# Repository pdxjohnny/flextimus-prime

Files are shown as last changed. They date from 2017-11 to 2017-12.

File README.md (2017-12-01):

# Flextimus Prime

Posture monitor

## Getting Started

Make sure you have git configured.

```console
git config --global user.name 'Frist Last'
git config --global user.email 'first.last@example.com'
```

Install the git commit hooks. This will ensure that you can only commit if the
source compiles successfully.

> **WARNING** This adds `set auto-load safe-path /` to your `~/.gdbinit` which
> is not safe because when you start gdb it will now execute any commands in the
> `.gdbinit` file in the current directory.

```console
./scripts/install.sh
```

Find out what you should work on

```console
git todo
```

> This will be run every time you pull so that see todos added by others.

Create a new branch for your work

```console
git checkout -b describe_my_intended_changes
```

Now connect the board, and start `st-util`. From the the top level of this repo
run `arm-none-eabi-gdb` or `make gdb`.

Start hacking!

### Dependencies

1. [mbed](https://os.mbed.com/docs/v5.6/tools/setup.html)

## Contributing

See [CONTRIBUTING.md](https://github.com/pdxjohnny/flextimus-prime/blob/master/CONTRIBUTING.md)

## Team

- Max (lead)
- Julian
- John
- fouric

> Fall 2017
> Practicum Project

## Description

Your team will be responsible for designing, constructing, and demonstrating a small project as part of the course. The project is intended to both give you some necessary implementation skills and experience as well as serve as a model for your capstone experience. In fact, the capstone evaluation forms and worksheets will be used in evaluating and grading your practicum project.

You will get experience with PCB schematic and layout tools, project documentation and management tools, revision control systems, PCB assembly, and (depending upon your project) microcontroller IDEs.

Equally important, you will create project requirements, test plans, schedules, and documentation as you would for your capstone project (or a project in industry). Requirements Your project can do almost anything but must satisfy the following course requirements:

- Have one or more inputs or sensors
  - e.g. photodiodes, switches, accelerometers, pressure sensor, network data (wired or wireless), etc.

- Have one or more outputs or transducers
  - e.g. LEDs, LCDs, motors, networking (wired or wireless).

- Have one or more processing modules which control some of the outputs based on the inputs
  - e.g. analog filters, microcontrollers, FPGAs, etc.

- Use a two layer PCB that is between 1 and 16 in 2, with no side of the board being less than 1 inch or more than 12 inches.

- Use components that can be hand soldered or easily soldered in a crude reflow oven (no BGAs, uBGAs, LGAs, or components smaller than 0603 packages allowed)

## Grading Criteria

Your project will be evaluated using the capstone evaluation forms found on the capstone web site.

Portions of your practicum are evaluated separately throughout the course as part of the homework assignments.

Other aspects are evaluated as part of your project demonstration (final project presentation, design documentation, communication (e.g. weekly progress reports)). Originality Ideally, you should choose an original project idea or a new implementation of an existing idea. To receive an A on the practicum project you must not use existing work (unless specifically approved in advance by the instructor in writing).

If you choose to implement an existing design or incorporate existing work (including but not limited to schematics, layout, or code), your maximum achievable grade is a B.

However, you must disclose both what you've borrowed and the source.

Use of existing work that is not disclosed will result in a practicum grade of F. Recommendation It's far more important that your project be complete and functioning than complex. It's essential that you complete all aspects of the project from idea generation through requirements definition, design description/modeling, layout, construction, test, debug, and documentation.

It's important that you demonstrate a working project. A simple project designed and implemented completely by the team using the disciplined design process taught in class and demonstrably working will beat out an overly ambitious project that's incomplete, non-functioning, or haphazardly implemented.

Consider this in choosing a project. That's not to suggest you shouldn't be imaginative or ambitious. Everything else being equal, a creative points.

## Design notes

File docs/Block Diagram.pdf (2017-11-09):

# Flextimus Prime

# Posture Detection Device

## Julian Saunders Max Schweitzer John Anderson Grant Vesely

Posture | Detection | Device: | Level | 0

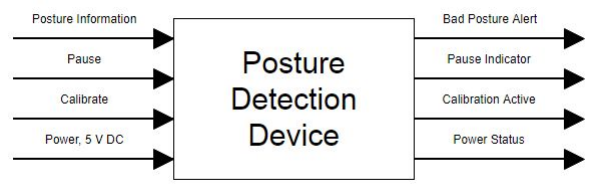
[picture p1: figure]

Module | Posture Detection Device
Inputs | Posture Information: The range of values from the sensor that are considered either good or bad for posture. Pause: Stop the alert system for some amount of time. Calibrate: Change range that the system defines as “good” posture. Power: 5 V DC source from USB connection.
Outputs | Bad Posture Alert: Signals the user that they have bad posture. Pause Indicator: Tells the user that the system is paused. Calibration Active: Tells the user that the system is in calibration mode. Power Status: Displays if the system has power.
Functionality | Takes a range of values from a flex sensor based on the user’s posture. The values considered good can be changed by the user. If the user’s posture is out of the acceptable range then they are notified by a buzzer. The notification of bad posture can be paused.

Posture | Detection | Device: | Level | 1

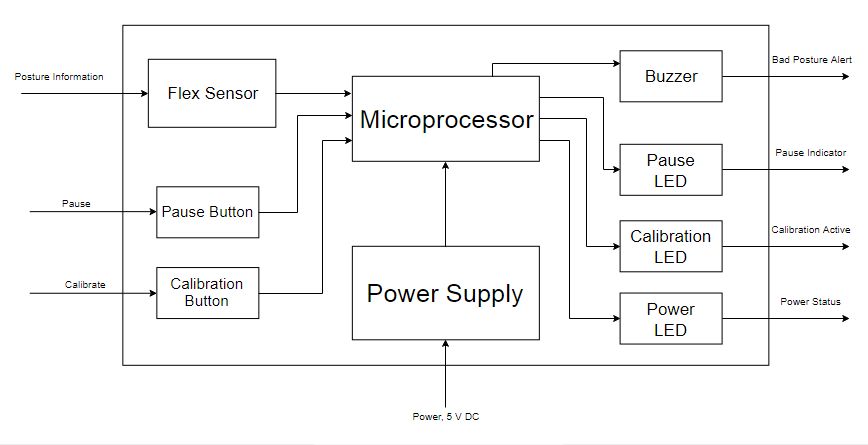
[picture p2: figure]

Microprocessor: | Level | 1

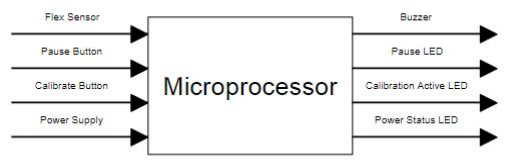
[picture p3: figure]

Module | Microprocessor
Inputs | Flex Sensor: Receives a variable voltage from the flex sensor. Pause Button: Signal to the processor to stop alerts. Calibrate Button: Signal to the processor to begin calibration. Power Supply: 3.3 V DC
Outputs | Buzzer: Signal to activate the buzzer alert. Pause LED: Signal to turn on the LED when paused.. Calibration LED: Signal to turn on the LED when calibrating. Power Status LED: Signal to LED indicating system has power.
Functionality | Receives signals from hardware and produces appropriate output signals based on the combination of input signals and code constraints. Does any necessary internal calculations.

Flex | Sensor: | Level | 1

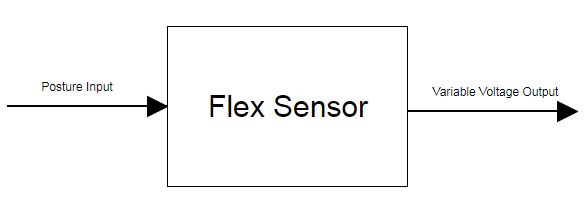
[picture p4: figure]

Module | Flex Sensor
Inputs | Posture Input: Based on how far the user moves their body (neck, back, wrists, etc.)
Outputs | Variable Voltage Output: Outputs a voltage that depends on how bent the flex sensor is.
Functionality | Converts how bent a desired part of the body is into a voltage value that can be used by the processor track posture. The resistance of the flex sensor changes with how much it is bent.

Pause | Button: | Level | 1

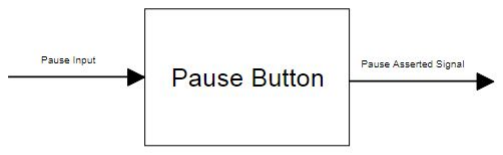
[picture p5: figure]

Module | Pause Button
Inputs | Pause Input: Button press from user.
Outputs | Pause Asserted Signal: Logic High.
Functionality | Gives the user a way to tell the processor to stop sending the alert signal for some period of time or potentially until pressed again.

Calibration | Button: | Level | 1

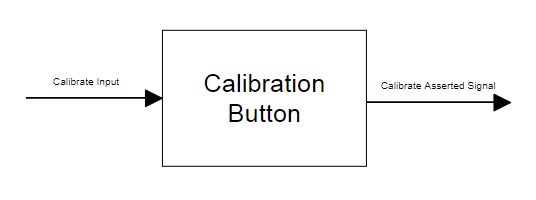
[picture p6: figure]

Module | Calibrate Button
Inputs | Calibrate Input: Button press from user.
Outputs | Calibrate Asserted Signal: Logic High.
Functionality | Allows the user to set their own desired range of accepted values for good posture.

Buzzer: | Level | 1

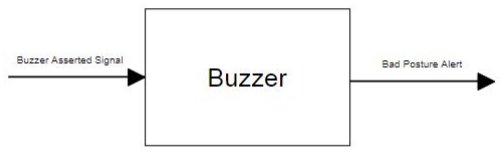
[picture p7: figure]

Module | Buzzer
Inputs | Buzzer Asserted Signal: Signal from processor when a posture violation has occurred.
Outputs | Bad Posture Alert: Buzzer activation
Functionality | Buzzer to vibrate and make noise to alert the user that their posture is bad. Stops when user resumes a good posture.

Pause | LED: | Level | 1

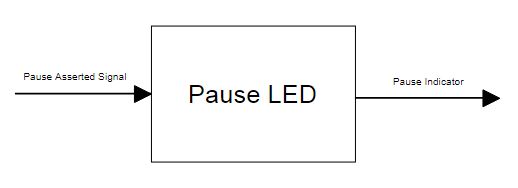
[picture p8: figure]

Module | Pause LED
Inputs | Pause Asserted Signal: Signal from processor that system is paused.
Outputs | Pause Indicator: LED turns on/off.
Functionality | LED that tells the user that the system is in pause mode when lit and bad posture violations will not be reported.

Calibrate | LED: | Level | 1

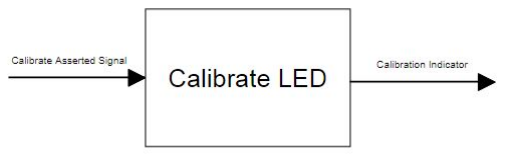
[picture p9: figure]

Module | Calibrate LED
Inputs | Calibrate Asserted Signal: Signal from processor that the system is in calibration mode.
Outputs | Calibration Indicator: LED turns on/off.
Functionality | When lit, indicates that the system is in calibration mode and is recording new maximum values for the range of legal motion.

Power | LED: | Level | 1

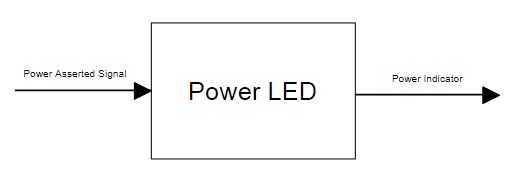
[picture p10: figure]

Module | Power LED
Inputs | Power Asserted Signal: Signal from processor or possibly tied to power supply.
Outputs | Power Indicator: LED turns on/off.
Functionality | LED on indicates the system has power.

Power | Supply: | Level | 1

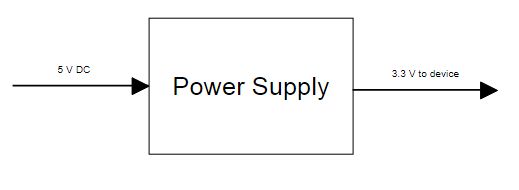
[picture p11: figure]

Module | Power Supply
Inputs | 5 V DC: Power
Outputs | 3.3 V to device: Power to the Microprocessor.
Functionality | Powers the device with desired values.

Power | Supply: | Level | 2

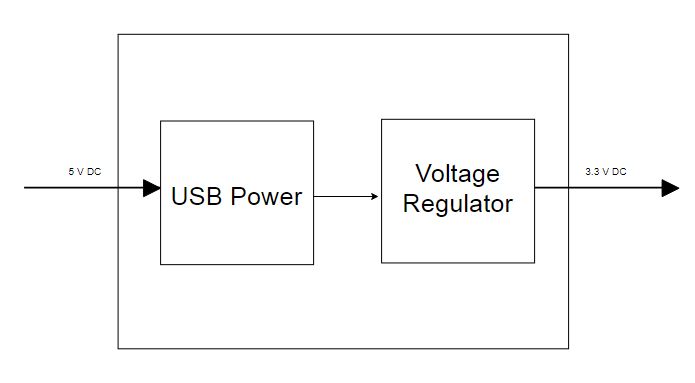
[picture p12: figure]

USB | Power: | Level | 2

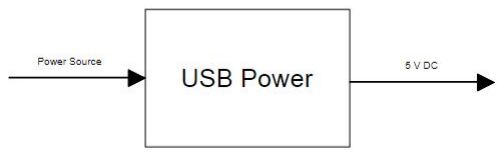
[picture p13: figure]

Module | USB Power
Inputs | Power Source: Plug from USB port.
Outputs | 5 V DC: Output to power supply system.
Functionality | Main connection for powering the device.

Voltage | Regulator: | Level | 2

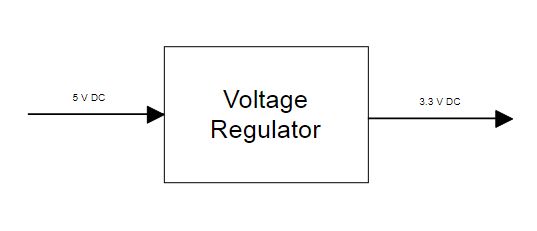
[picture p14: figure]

Module | Voltage Regulator
Inputs | 5 V DC: From USB power.
Outputs | 3.3 V DC: to processor.
Functionality | Converts the 5 volt input from the USB power to 3.3 volts for the processor.

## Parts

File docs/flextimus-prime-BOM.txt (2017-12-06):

Partlist exported from C:/Users/Crimson/AppData/Local/Temp/Rar$DIa0.229/flextimus-prime.sch at 11/30/2017 9:41 PM

Part Value             Device                          Package                  Description                                       COPYRIGHT                                                 MANUFACTURER_PART_NUMBER MF MPN OC_FARNELL OC_NEWARK PROD_ID     SF_SKU    TP_SIGNAL_NAME VALUE    VENDOR            
C1   100n              C-EUC0805                       C0805                    CAPACITOR, European symbol                                                                                                                                                                                                       
C2   100n              C-EUC0805                       C0805                    CAPACITOR, European symbol                                                                                                                                                                                                       
C4   10uf              C-EUC0805                       C0805                    CAPACITOR, European symbol                                                                                                                                                                                                       
C5   10uf              C-EUC0805                       C0805                    CAPACITOR, European symbol                                                                                                                                                                                                       
C6   0.1uf             C-EUC0805                       C0805                    CAPACITOR, European symbol                                                                                                                                                                                                       
C7   10uf              C-EUC0805                       C0805                    CAPACITOR, European symbol                                                                                                                                                                                                       
C8   0.1uf             C-EUC0805                       C0805                    CAPACITOR, European symbol                                                                                                                                                                                                       
CN2                    USBMINIB                        USB-MINIB                USB Connectors                                                                                                                                                                                                                   
D1                     LED10MM                         LED_10MM                 LED (Generic)                                                                                                                                                                                                                    
D2                     LED10MM                         LED_10MM                 LED (Generic)                                                                                                                                                                                                                    
D3                     LED10MM                         LED_10MM                 LED (Generic)                                                                                                                                                                                                                    
FB1  2.5kO/50mA        FERRITE_BEAD-0603               0603                     Ferrite Bead (blocks, cores, rings, chokes, etc.)                                                                                                                NDUC-07859                           30O/1.8A                   
JP1                    PINHD-1X2                       1X02                     PIN HEADER                                                                                                                                                                                                                       
JP2                    PINHD-1X2                       1X02                     PIN HEADER                                                                                                                                                                                                                       
JP3                    PINHD-1X16                      1X16                     PIN HEADER                                                                                                                                                                                                                       
JP5                    JP1E                            JP1                      JUMPER                                                                                                                                                                                                                           
JP6                    PINHD-2X10                      2X10                     PIN HEADER                                                                                                                                                                                                                       
R1   6k                R-US_R0805                      R0805                    RESISTOR, American symbol                                                                                                                                                                                                        
R2   6k                R-US_R0805                      R0805                    RESISTOR, American symbol                                                                                                                                                                                                        
R3   330               R-US_R0805                      R0805                    RESISTOR, American symbol                                                                                                                                                                                                        
R4   330               R-US_R0805                      R0805                    RESISTOR, American symbol                                                                                                                                                                                                        
R5   10k               R-US_R0805                      R0805                    RESISTOR, American symbol                                                                                                                                                                                                        
R6   10k               R-US_R0805                      R0805                    RESISTOR, American symbol                                                                                                                                                                                                        
R7   10k               R-US_R0805                      R0805                    RESISTOR, American symbol                                                                                                                                                                                                        
R8   10k               R-US_R0805                      R0805                    RESISTOR, American symbol                                                                                                                                                                                                        
R9   10k               R-US_R0805                      R0805                    RESISTOR, American symbol                                                                                                                                                                                                        
R10  10k               R-US_R0805                      R0805                    RESISTOR, American symbol                                                                                                                                                                                                        
S1   SPST              MOMENTARY-SWITCH-SPST-PTH-6.0MM TACTILE_SWITCH_PTH_6.0MM Momentary Switch (Pushbutton) - SPST                                                                                                                              SWCH-08441 COM-00097                                           
S2   SPST              MOMENTARY-SWITCH-SPST-PTH-6.0MM TACTILE_SWITCH_PTH_6.0MM Momentary Switch (Pushbutton) - SPST                                                                                                                              SWCH-08441 COM-00097                                           
SG1  F/CM04P           F/CM04P                         F/CM04P                  BUZZER Source: Buerklin                                                                                                                     unknown    unknown                                                                   
T1   2N2222            2N2222                          TO92-EBC-OVAL            NPN TRANSISTOR                                                                                                                                                                                                                   
TP1  TPB2,54           TPB2,54                         B2,54                    Test pad                                                                                                                                                                                                                         
TP2  TPB2,54           TPB2,54                         B2,54                    Test pad                                                                                                                                                                                                                         
TP3  TPB2,54           TPB2,54                         B2,54                    Test pad                                                                                                                                                                                                                         
TP4  TPB2,54           TPB2,54                         B2,54                    Test pad                                                                                                                                                                                                                         
TP5  TPB2,54           TPB2,54                         B2,54                    Test pad                                                                                                                                                                                                                         
TP6  TPB2,54           TPB2,54                         B2,54                    Test pad                                                                                                                                                                                                                         
TP7  TPB2,54           TPB2,54                         B2,54                    Test pad                                                                                                                                                                                                                         
TP8  TPB2,54           TPB2,54                         B2,54                    Test pad                                                                                                                                                                                                                         
U1   STM32F042KXU      STM32F042KXU                    UFQFPN32-5X5MM           STM32F042K6U6                                     Copyright C 2016 Accelerated Designs. All rights reserved stm32f042kxu                                                                                       STMicroelectronics
U3   MCP1802T-3302I/OT MCP1802T-3302I/OT               SOT-23-5_MC                                                                                                                          MCP1802T3302IOT                                                                                    Microchip         
LCD Screen - 16x2 3.3V (ST7066/HD44780)
JTAG pin headers
LCD screen pin headers

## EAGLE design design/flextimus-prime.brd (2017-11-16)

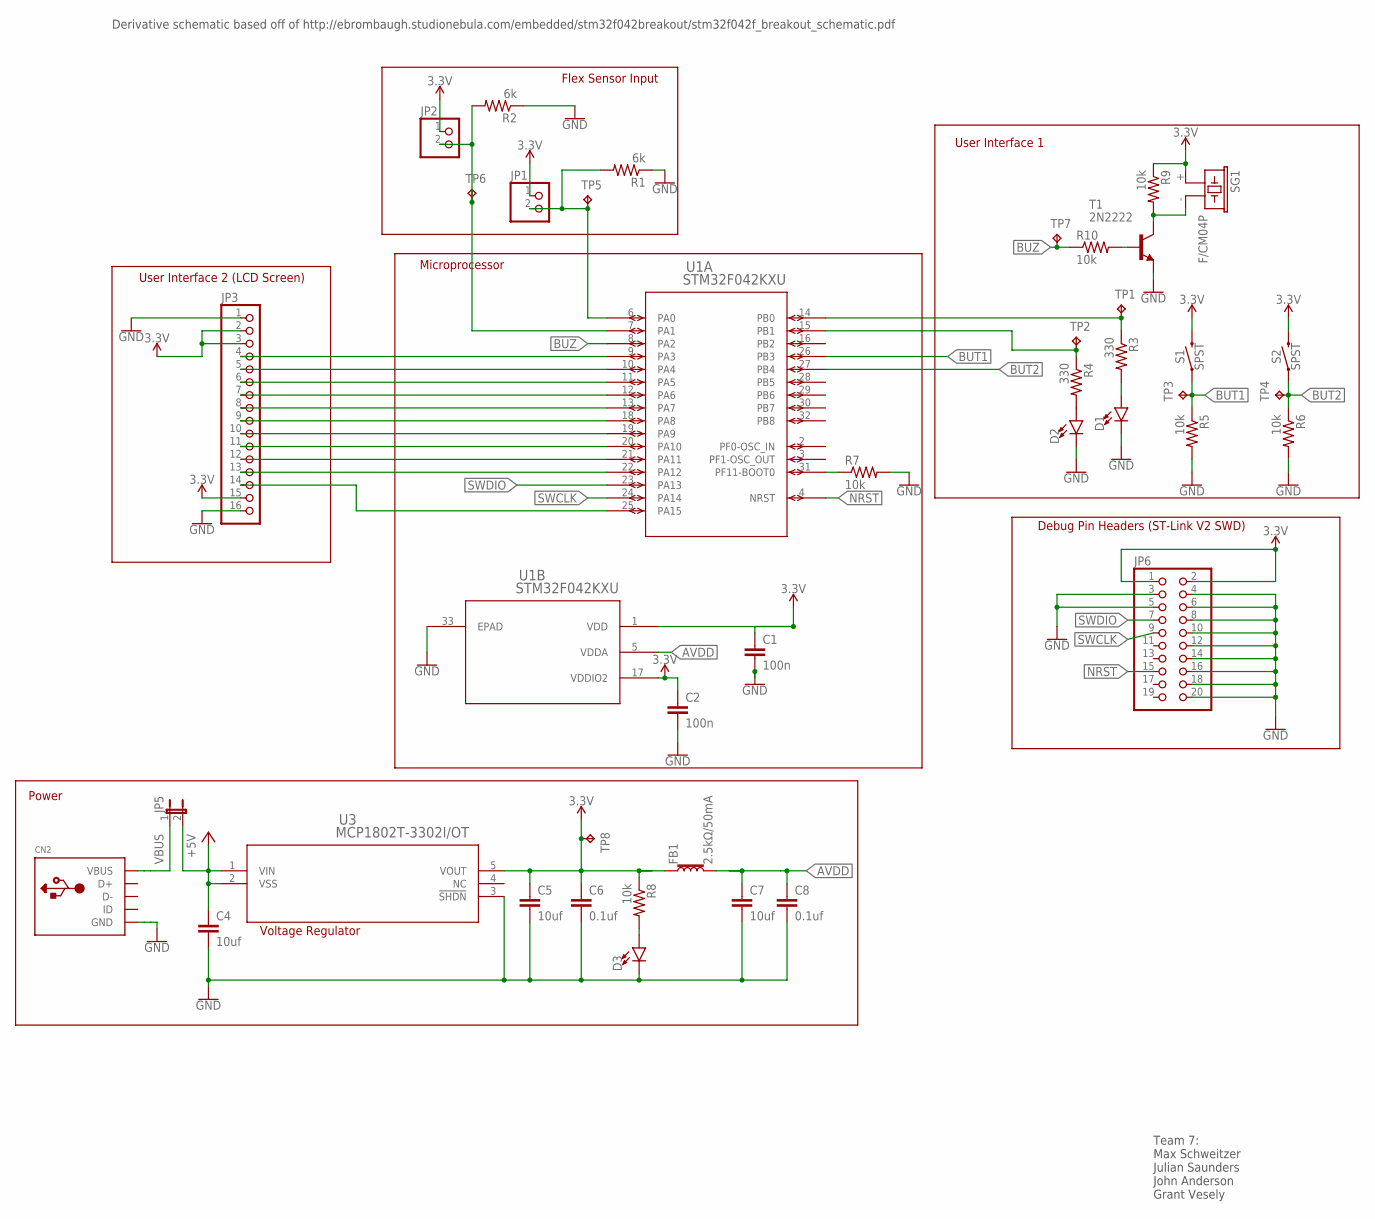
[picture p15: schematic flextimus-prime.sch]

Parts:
C1, C2: 100n; C0805
C4, C5, C7: 10uf; C0805
C6, C8: 0.1uf; C0805
CN2: USBMINIB; USB-MINIB
D1, D2, D3: LED10MM; LED_10MM
FB1: 2.5kΩ/50mA; 0603
JP1, JP2: PINHD-1X2; 1X02
JP3: PINHD-1X16; 1X16
JP5: JP1E; JP1
JP6: PINHD-2X10; 2X10
R1, R2: 6k; R0805
R3, R4: 330; R0805
R5, R6, R7, R8, R9, R10: 10k; R0805
S1, S2: SPST; TACTILE_SWITCH_PTH_6.0MM
SG1: F/CM04P
T1: 2N2222; TO92-EBC-OVAL
TP1, TP2, TP3, TP4, TP5, TP6, TP7, TP8: TPB2,54; B2,54
U1: STM32F042KXU; UFQFPN32-5X5MM
U3: MCP1802T-3302I/OT; SOT-23-5_MC

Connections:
3.3V: C1.1, C2.1, C5.1, C6.1, FB1.1, JP1.1, JP2.1, JP3.2, JP3.3, JP3.15, JP6.1, JP6.2, R8.1, R9.1, S1.3 (2), S2.3 (2), SG1.+ (1), TP8.TP, U1.1 (VDD), U1.17 (VDDIO2), U3.5 (VOUT)
+5V: C4.1, JP5.2, U3.1 (VIN), U3.2 (VSS)
AVDD: C7.1, C8.1, FB1.2, U1.5 (VDDA)
BUT1: R5.1, S1.1, TP3.TP, U1.26 (PB3)
BUT2: R6.1, S2.1, TP4.TP, U1.27 (PB4)
BUZ: R10.1, TP7.TP, U1.8 (PA2)
GND: C1.2, C2.2, C4.2, C5.2, C6.2, C7.2, C8.2, CN2.GND, D1.C, D2.C, D3.C, JP3.1, JP3.16, JP6.3, JP6.4, JP6.5, JP6.6, JP6.8, JP6.10, JP6.12, JP6.14, JP6.16, JP6.18, JP6.20, R1.1, R2.1, R5.2, R6.2, R7.2, T1.E, U1.33 (EPAD), U3.3 (!SHDN)
unnamed: JP1.2, R1.2, TP5.TP, U1.6 (PA0)
unnamed: JP2.2, R2.2, TP6.TP, U1.7 (PA1)
unnamed: R3.1, TP1.TP, U1.14 (PB0)
unnamed: JP3.14, U1.25 (PA15)
unnamed: D1.A, R3.2
unnamed: D2.A, R4.2
unnamed: R9.2, SG1.- (2), T1.C
unnamed: R10.2, T1.B
unnamed: D3.A, R8.2
unnamed: JP3.4, U1.9 (PA3)
unnamed: JP3.5, U1.10 (PA4)
unnamed: JP3.6, U1.11 (PA5)
unnamed: JP3.7, U1.12 (PA6)
unnamed: JP3.8, U1.13 (PA7)
unnamed: JP3.9, U1.18 (PA8)
unnamed: JP3.10, U1.19 (PA9)
unnamed: JP3.11, U1.20 (PA10)
unnamed: JP3.12, U1.21 (PA11)
unnamed: JP3.13, U1.22 (PA12)
unnamed: R7.1, U1.31 (PF11-BOOT0)
unnamed: R4.1, TP2.TP, U1.15 (PB1)
NRST: JP6.15, U1.4 (NRST)
SWCLK: JP6.9, U1.24 (PA14)
SWDIO: JP6.7, U1.23 (PA13)
VBUS: CN2.VBUS, JP5.1

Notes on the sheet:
Derivative schematic based off of http://ebrombaugh.studionebula.com/embedded/stm32f042breakout/stm32f042f_breakout_schematic.pdf
Power
User Interface 1
Debug Pin Headers (ST-Link V2 SWD)
Voltage Regulator
Flex Sensor Input
User Interface 2 (LCD Screen)
Microprocessor
Team 7: Max Schweitzer Julian Saunders John Anderson Grant Vesely

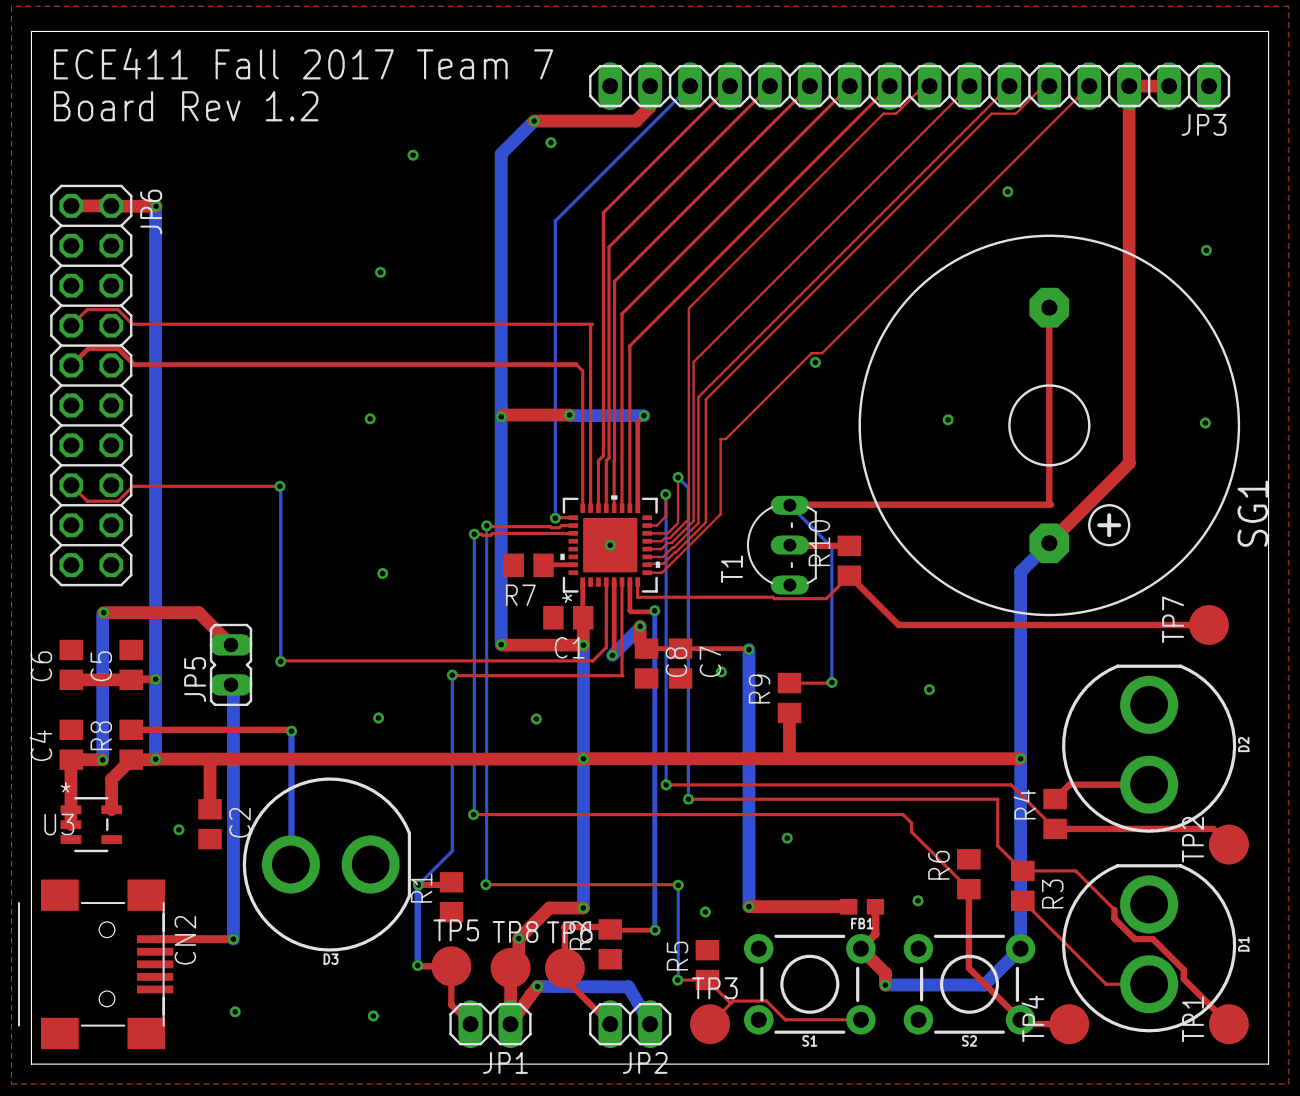
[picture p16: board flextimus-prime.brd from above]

Board: 2 copper layers, 78.7 x 65.7 mm, 41 parts (0 on the bottom side), 32 nets.

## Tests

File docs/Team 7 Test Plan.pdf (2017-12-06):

# Team 7 Test Plan Flextimus-Prime

## Authors:

### Max Schweitzer Julian Saunders John Anderson Grant Vesely

Revision Number | Date
1.0 | 11/30/17

T

a

# ble

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
e | o
f | C

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
al T

e

s

t

O

u

tlin

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
al T

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
# Introduction

This document is intended to ensure the system functions as a whole by testing from the ground up. By testing from the bottom up we can ensure any single point of failure due to hardware or software is quickly identified and fixed.

## Objectives

The overall objective of this test plan is to test the flextimus-prime posture detector in a piece by piece fashion, using a combination of unit testing, functional testing, and error testing to ensure a robust product. The unit testing allows us to individually test the functionality of one module by itself, ensuring it will behave as expected before we integrate it with the other modules. Functional testing will be used to ensure we meet the features and abilities defined within our requirements specification, linked below. Error testing will help to ensure a robust system, and to minimize final bugs in the finished product.

# Reference Documentation

Document Name | Description | Link
Requirements Specification | Official requirements specification document detailing various needs, mays, and shoulds of the project. | https://github.com/pdxjohnny/flextimus-prime/wiki/Require ments (https://github.com/pdxjohnny/flextimus-prime/wiki/Requirements)
Block Diagram | High level block view of total system and subsystems | https://github.com/pdxjohnny/flextimus-prime/blob/master/B lock%20Diagram.pdf (https://github.com/pdxjohnny/flextimus-prime/blob/master/Block%20Diagram.pdf)
Final Schematic | Eagle schematic file. | https://github.com/pdxjohnny/flextimus-prime/blob/master/fl extimus-prime.sch (https://github.com/pdxjohnny/flextimus-prime/blob/master/flextimus-prime.sch)
Final Board | Eagle board layout file. | https://github.com/pdxjohnny/flextimus-prime/blob/master/fl extimus-prime.brd (https://github.com/pdxjohnny/flextimus-prime/blob/master/flextimus-prime.brd)

# Testing Plan

## Hierarchical Test Outline

### Unit Testing

Unit testing involves testing each individual part before testing it in any sort of combination with other parts. This ensures that we can find any single point of error due to hardware faults early on in the testing process.

Objectives:
- Component meets individual functional requirements
- Black box / white box tests pass
- Component meets design requirements for system

Test cases:
- Test power supply [UT-PWR1]
- System is being powered by USB port with correct voltages.
- Test power supply connections [UT-PWR2]
- Each individual component is receiving power from the power supply.
- Test Config button [UT-BTN1]
- Button sends signal when asserted.
- Test Pause button [UT-BTN2]
- Button sends signal when asserted.
- Test Config LED [UT-LED1]
- LED lights when signal received.
- Test Pause LED [UT-LED2]
- LED lights when signal received.
- Test Buzzer [UT-BZR1]
- Buzzer sounds when signal received.
- Test LCD screen [UT-LCD1]
- LCD screen turns on and visibly works, can be sent messages to display text.
- Test Flex sensor [UT-FLX1]
- Flex sensor shows voltage change when bent.

### Functional Testing

Functional testing involves testing how one or more parts interact with each other. Ideally we want to test at the lowest levels of functionality, just above unit testing. Once we know that a sub-function works, we can rule it out as a potential source of error in the higher level functionality. Additionally, we are testing for basic functionality of the system as well.

Objectives:
- Verify that components in subsystems function properly.
- Fix any hardware issues between components.
- Fix any software bugs that cause complete failures of the subsystem.
- Verify basic functionality

Test cases:
- Test Config mode [FT-CFG1]
- Configuration mode begins when config button is pressed
- Test Pause mode [FT-PSE1]
- Pause mode begins when pause button is pressed
- Test posture recording [FT-PST1]
- Values for good posture are recorded correctly
- Test posture violation [FT-PST2]
- Program detects suboptimal posture
- Test alert on a violation [FT-PST3]
- Buzzer sounds when posture violation signal is received

### Error Testing

Error testing involves interacting with the device in a way that it is not meant to function. We want to ensure that the system can continue to function properly when unexpected or undesired user input is detected.

Objectives:
- System functions as intended when used correctly.
- System does not fail when unexpected inputs are entered. Test Cases:
- Test flex sensor errors [ET-TST1]
- No warnings if flex sensor is bent the wrong way
- Test multiple simultaneous button input [ET-TST2]
- Arbitration if pause and config buttons are pressed simultaneously
- Test incorrect button sequence [ET-TST3]
- No errors if wrong button sequence is pressed, i.e. config and then pause
- Test config timeout [ET-TST4]
- Config function times out after not receiving user input after some time limit

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
el: ● Max
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
ulia

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
t: ● Sold
e

r ir

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
ultim

e

t

e

r
- | ST-Link | v2

C

o

m

p

o

| n e n t s / B | o a

r

d

s: Flextimus-prime boar
d

R

e

visio

n

1.2
Bill o

f

M

a

t

e

rials (https://github.com/pdxjohnny/flextimus-prime/blob/master/flextimus-prime-BOM.txt)

S

o

ft

w

a

r

e: ● EA
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
til ● ST Lin
k

U

tilit

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
al P

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
s: ● Linux ● Windows 7/1

0

## Detailed Test Cases

Test Writer: Julian Saunders

Test Case Name: | Test Config mode | Test ID #: | FT-CFG1
Description: | Configuration mode begins when config button is pressed and iterates through the config sequence correctly when subsequent buttons are pressed. | Type: | White Box

Tester Information

Name of Tester: | | Date:
Hardware Ver: | 1.0 | Time:
Setup: | Power up the system with the flex sensor and configuration button enabled in the software. Only input will be through the sensor and button themselves. View outputs on LCD screen.
Step | Action | Expected Result | Pass | Fail | Comments
1 | First press of config button. | “Mode: Config” appears on screen.
2 | Adjust (bend) sensor to desired min and max position. | -
3 | Second press of config button. | Config mode is exited, min and max values are new monitor values. “Mode: Monitoring” appears on screen.

Overall test results:

Test Writer: Julian Saunders

Test Case Name: | Test button sequence | Test ID #: | ET-TST3
Description: | System does not fault when incorrect buttons are pressed for different sequences. | Type: | White Box

Tester Information

Name of Tester: | | Date:
Hardware Ver: | 1.0 | Time:
Setup: | Whole system is booted up. Only inputs tested will be user input by config and pause buttons. System should continue to function without faults, showing outputs on screen.
Step | Action | Expected Result | Pass | Fail | Comments
1 | Press config button | “Mode: Config” appears on screen.
2 | Press pause button | System stays in config mode
3 | Finish config sequence by pressing config button again. | Sequence configures correctly and resumes to Monitoring mode, displaying “Mode: Monitoring” on screen.
4 | Press pause button | “Mode: Paused” appears on screen.
5 | Press config button | System stays in pause mode
6 | Press pause button | Sequence ends pause mode correctly and

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
e. Shows “Mode: Monitoring” on screen. Overall test results:

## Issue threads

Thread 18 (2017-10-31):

Development Board Boot Up Documentation

pdxjohnny, 2017-10-31:

pdxjohnny, 2017-11-12:
## Embedded boot loader
> 2.5 DocID018940 REv 9

The embedded boot loader is located in the System memory, programmed by ST during
production. It is used to reprogram the Flash memory using one of the following serial
interfaces:
• USART on pins PA14/PA15 or PA9/PA10
• I2C on pins PB6/PB7 (STM32F04xxx, STM32F07xxx and STM32F09xxx devices only)
• USB DFU interface (STM32F04xxx and STM32F07xxx devices only)
For further details, please refer to AN2606.

fouric, 2017-12-06:
i think we got it working, can we close?

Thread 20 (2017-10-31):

Sensor Driver Code

pdxjohnny, 2017-10-31:
1. ADC can generate interrupts at the end of sampling, end of conversion, end of sequence
conversion, and in case of analog watchdog or overrun events.

pdxjohnny, 2017-11-13:
#41 provides the ST libs for talking to the ADC, will work on this soon

Closed 2017-12-06.

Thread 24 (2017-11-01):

Order Parts

Crimson89, 2017-11-01:
Order all of the parts for the project for all four group members

pdxjohnny, 2017-11-01:
Depends on #15

pdxjohnny, 2017-11-13:
Let's update the status on this, I remember some discussion in discord

fouric, 2017-11-25:
I'm an idiot and shipped my parts (LEDs, buttons, headers, USB connectors) to my internship address...in Maryland. Re-ordering now, parts should be here by the end of next week, and I can substitute in some of my own in the meantime.

fouric, 2017-11-25:
Wow, twice the fool, double the problems; when I re-ordered, I only got six buttons, instead of twelve.

fouric, 2017-12-06:
Order'd

Closed 2017-12-06.

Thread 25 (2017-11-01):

STM32 GPIO addresses

Crimson89, 2017-11-01:
Write a document for all of the memory mapped GPIO addresses for later use in our code.

pdxjohnny, 2017-11-13:
Added the ST headers and driver code in #41

Closed 2017-11-13.

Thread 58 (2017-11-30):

Fix ADC watchdog interrupt

MaxMSchweitzer, 2017-11-30:

MaxMSchweitzer, 2017-11-30:
@pdxjohnny

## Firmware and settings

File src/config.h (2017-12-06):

#ifndef _CONFIG_H_
#define _CONFIG_H_

/* Outputs */
#define PAUSE_LED           GPIO_B0
#define CONFIG_LED          GPIO_B1

/* Inputs */
#define FLEX_SENSOR         GPIO_A0
#define PAUSE_BUTTON        GPIO_B3
#define CONFIG_BUTTON       GPIO_B4
#define BUZZER              GPIO_A2

/* Buzzer only allowed to be on for so long while configuring */
#define BUZZER_TIMEOUT 500

#define DEFAULT_MIN    1200
#define DEFAULT_MAX    1400

#endif /* _CONFIG_H_ */

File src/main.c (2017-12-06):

#include <adc.h>
#include <gpio.h>
#include <flextimus.h>
#include "config.h"
#include "hd44780.h"
#include <stm32f042.h>

/* The state of Flextimus Prime. This controls the main loop. */
typedef enum {
  FLEXTIMUS_PRIME_ON,
  FLEXTIMUS_PRIME_OFF,
  FLEXTIMUS_PRIME_SLEEP,
} flextimus_prime_state_t;

/* The ADC state type lets us keep track of what we should be doing with the ADC
 * when we get interrupts. */
typedef enum {
  ADC_IDLE,
  ADC_READY,
  ADC_CONVERTED,
} adc_state_t;

/* One global to rule them all */
struct {
  bool paused;
  bool configuring;
  bool buzzer_timedout;
  unsigned int buzzer_timeout;
  struct {
    uint32_t max;
    uint32_t min;
    uint32_t curr;
    uint32_t volts;
    uint32_t millivolts;
    adc_state_t state;
  } adc;
  flextimus_prime_state_t state;
} flextimus_prime;

void adc_null_callback() {}

void assert_failed(uint8_t* file, uint32_t line) {
  while (1) {}
}

void flextimus_prime_default_bounds() {
  flextimus_prime.adc.min = flextimus_prime.adc.curr;
  flextimus_prime.adc.max = flextimus_prime.adc.curr;
}

void flextimus_prime_init() {
  flextimus_prime.paused = false;
  flextimus_prime.configuring = false;
  flextimus_prime.buzzer_timeout = 0;
  flextimus_prime.buzzer_timedout = false;
  flextimus_prime.adc.state = ADC_IDLE;
  flextimus_prime.adc.min = DEFAULT_MIN;
  flextimus_prime.adc.max = DEFAULT_MAX;
}

void configure_gpios() {
	// Power up PORTA
	RCC_AHBENR |= BIT17;
	// Power up PORTB
	RCC_AHBENR |= BIT18;

  // Set Inputs
  /*
  gpio_input(PAUSE_BUTTON);
  gpio_input(CONFIG_BUTTON);
  */
  GPIOB_MODER |= BIT6; // BTN1 - Pause
  GPIOB_MODER &= ~BIT7; // "" B3
  GPIOB_MODER |= BIT8; // BTN2 - Config
  GPIOB_MODER &= ~BIT9; // "" B4

  // Set Outputs
  /*
  gpio_up(BUZZER);
  gpio_up(PAUSE_LED);
  gpio_up(CONFIG_LED);
  */
  GPIOA_MODER |= BIT4; // Buzzer
  GPIOA_MODER &= ~BIT5; // "" A2
  GPIOB_MODER |= BIT0; // LED1 - Pause
  GPIOB_MODER &= ~BIT1; // "" B0
  GPIOB_MODER |= BIT2; // LED2 - Config
  GPIOB_MODER &= ~BIT3; // "" B1
}

bool LCD_Written = false;
bool bad_posture_message = false;
bool configured = false;


int main(void) {
  unsigned int curr;
  bool running = true;
  adc_status_t adc_status;
  debouncer_t debounce_pause, debounce_config;

  debounce_init(&debounce_pause);
  debounce_init(&debounce_config);

  flextimus_prime_init();

  __disable_irq();

  configure_gpios();

  adc_status = adc_up(FLEX_SENSOR, adc_null_callback);
  if (ADC_ERROR(adc_status)) {
    assert_failed(__FILE__, __LINE__);
  }


  // Start displaying on the LCD.
  HD44780_Setup();
  HD44780_PowerOn();
  HD44780_Clear();
  HD44780_Puts((uint8_t *)"Mode: Standby");
  HD44780_GotoXY(0,1);
  HD44780_Puts((uint8_t *)"Please Configure");

  gpio_off(BUZZER);
  gpio_off(PAUSE_LED);
  gpio_off(CONFIG_LED);

  while (running) {
    /* Read from ADC forever */
    adc_status = adc_read();
    flextimus_prime.adc.curr = adc_status.data;
    /* Set the volts and millivolts for our debugging convenience in GDB */
    flextimus_prime.adc.volts = ADC_VOLTS(flextimus_prime.adc.curr);
    flextimus_prime.adc.millivolts = ADC_MILLIVOLTS(flextimus_prime.adc.curr);
    /* Button press handlers */
    if (gpio_asserted_debounce(PAUSE_BUTTON, &debounce_pause)) {
      flextimus_prime_pause_pressed();
    } else if (gpio_asserted_debounce(CONFIG_BUTTON, &debounce_config)) {
      flextimus_prime_config_pressed();
    }
    /* Configuration */
    if (flextimus_prime.configuring == true) {
      if (flextimus_prime.adc.curr > flextimus_prime.adc.max) {
        flextimus_prime.adc.max = flextimus_prime.adc.curr;
      }
      if (flextimus_prime.adc.curr < flextimus_prime.adc.min) {
        flextimus_prime.adc.min = flextimus_prime.adc.curr;
      }
    }
    /* If we are within range OR set to defaults OR timed out then turn off the
     * buzzer */
    if ((((flextimus_prime.adc.curr < flextimus_prime.adc.max) &&
        (flextimus_prime.adc.curr > flextimus_prime.adc.min)))) {
      gpio_off(BUZZER);
      bad_posture_message = false;
      if (!LCD_Written)
      {
        HD44780_Clear();
        HD44780_GotoXY(6,0);
        HD44780_Puts((uint8_t *)"Mode: Monitor");
        HD44780_GotoXY(0,1);
        HD44780_Puts((uint8_t *)"In Range");
        LCD_Written = true;
      }
    // If we are out of range and have been configured, sound the annoying buzzer
    } else if ((((flextimus_prime.adc.curr > flextimus_prime.adc.max) ||
              (flextimus_prime.adc.curr < flextimus_prime.adc.min))  &&
              flextimus_prime.paused == false) && configured == true) {
      ++flextimus_prime.buzzer_timeout;
      //if (flextimus_prime.buzzer_timeout > BUZZER_TIMEOUT) {
      //  flextimus_prime.buzzer_timedout = true;
      //}
      if (flextimus_prime.paused == false &&
          flextimus_prime.buzzer_timedout == false) {
        gpio_on(BUZZER);
        flextimus_prime.buzzer_timedout = false;
        flextimus_prime.buzzer_timeout = 0;
        
        if (bad_posture_message == false)
        { 
          bad_posture_message = true;
          HD44780_Clear();
          HD44780_GotoXY(6,0);
          HD44780_Puts((uint8_t *)"Mode: Monitor");
          HD44780_GotoXY(0,1);
          HD44780_Puts((uint8_t *)"Bad posture");
          LCD_Written = false;
        }
      }
    }
    switch (flextimus_prime.state) {
    case FLEXTIMUS_PRIME_SLEEP:
      PWR_EnterSleepMode(PWR_SLEEPEntry_WFI);
    case FLEXTIMUS_PRIME_OFF:
      running = false;
    case FLEXTIMUS_PRIME_ON:
    default:
      continue;
    }
  }

  gpio_down(BUZZER);
  gpio_down(PAUSE_LED);
  gpio_down(CONFIG_LED);

  gpio_down(PAUSE_BUTTON);
  gpio_down(CONFIG_BUTTON);

  adc_status = adc_down(FLEX_SENSOR);
  if (ADC_ERROR(adc_status)) {
    assert_failed(__FILE__, __LINE__);
  }

  /* The fall of Flextimus Prime */
  assert_param(NULL);

  return 0;
}

// Function to pause the alert system
void flextimus_prime_pause_pressed() {
  if (flextimus_prime.paused == false && flextimus_prime.configuring == false) { 
    
    HD44780_Clear();
    HD44780_GotoXY(6,0);
    HD44780_Puts((uint8_t *)"Mode: Paused");
    HD44780_GotoXY(0,1);
    HD44780_Puts((uint8_t *)"Peace and quiet");
    flextimus_prime.paused = true;
    gpio_on(PAUSE_LED);
  } else if (flextimus_prime.paused == true){ 
 
    HD44780_Clear();
    HD44780_GotoXY(6,0);
    HD44780_Puts((uint8_t *)"Mode: Monitor");
    HD44780_GotoXY(0,1);
    HD44780_Puts((uint8_t *)"In Range");
    flextimus_prime.paused = false;
    gpio_off(PAUSE_LED);
    LCD_Written = false;
  }
  Delay(200000);
}

void flextimus_prime_config_pressed() {
  adc_status_t adc_status;

  if (flextimus_prime.configuring == false && flextimus_prime.paused == false) {

    HD44780_Clear();
    HD44780_GotoXY(6,0);
    HD44780_Puts((uint8_t *)"Mode: Configure");
    HD44780_GotoXY(0,1);
    HD44780_Puts((uint8_t *)"Configuring");
    /* Start configuring */
    flextimus_prime_default_bounds();
    flextimus_prime.buzzer_timeout = 0;
    flextimus_prime.buzzer_timedout = false;
    flextimus_prime.configuring = true;
    gpio_on(CONFIG_LED);
  } else if (flextimus_prime.configuring == true) { 
    
    flextimus_prime.configuring = false;
    gpio_off(CONFIG_LED);
    LCD_Written = false;
    configured = true;
  }
  Delay(200000);
}

// IRQ handler for both button interrupts
void button_irq_handler() {
  if (gpio_asserted_irq(PAUSE_BUTTON)) {
    flextimus_prime_pause_pressed();
  } else if (gpio_asserted_irq(CONFIG_BUTTON)) {
    flextimus_prime_config_pressed();
  }
}

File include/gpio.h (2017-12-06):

#ifndef _GPIO_H_
#define _GPIO_H_

#include <flextimus.h>
#include <stdint.h>

/* A gpio_pin_t is just the uint16_t of the pin combined with a bit for which
 * GPIO peripheral the pin is on. */
typedef uint32_t gpio_pin_t;

#define GPIO_A            0x00010000
#define GPIO_B            0x00020000
#define GPIO_C            0x00040000

/* All GPIO pins fit within the lower 16 bits. */
#define GPIO_PIN_MASK     0x0000FFFF
#define GPIO_A0           (GPIO_A | GPIO_Pin_0)
#define GPIO_A2           (GPIO_A | GPIO_Pin_2)
#define GPIO_B0           (GPIO_B | GPIO_Pin_0)
#define GPIO_B1           (GPIO_B | GPIO_Pin_1)
#define GPIO_B3           (GPIO_B | GPIO_Pin_3)
#define GPIO_B4           (GPIO_B | GPIO_Pin_4)

#define DEBOUNCE_DELAY    750

typedef struct {
  unsigned int tick;
  uint32_t value;
} debouncer_t;

void* gpio_perf(gpio_pin_t gpio_pin);
void gpio_clock(gpio_pin_t gpio_pin, FunctionalState NewState);
void gpio_up(gpio_pin_t gpio_pin);
void gpio_input(gpio_pin_t gpio_pin);
void gpio_down(gpio_pin_t gpio_pin);
void gpio_on(gpio_pin_t gpio_pin);
void gpio_off(gpio_pin_t gpio_pin);
void gpio_input(gpio_pin_t gpio_pin);
bool gpio_asserted(gpio_pin_t gpio_pin);
void debounce_init(debouncer_t *debounce);
bool gpio_asserted_debounce(gpio_pin_t gpio_pin, debouncer_t *debounce);
bool gpio_asserted_irq(gpio_pin_t gpio_pin);

#endif /* _GPIO_H_ */

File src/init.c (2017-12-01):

#include <interrupt_handler.h>
void init(void);
int main(void);
void button_irq_handler(void);
void Default_Handler(void);
void debug_printIPSR(void);
// The following are 'declared' in the linker script
extern unsigned char  INIT_DATA_VALUES;
extern unsigned char  INIT_DATA_START;
extern unsigned char  INIT_DATA_END;
extern unsigned char  BSS_START;
extern unsigned char  BSS_END;
// the section "vectors" is placed at the beginning of flash
// by the linker script
const void * Vectors[] __attribute__((section(".vectors"))) ={
	(void *)0x20001000, 	/* Top of stack (4k) */
	init,   		/* Reset Handler */
	Default_Handler,	/* NMI */
	Default_Handler,	/* Hard Fault */
	Default_Handler,	/* MemManage */
	Default_Handler,	/* Reserved  */
	Default_Handler,	/* Reserved */
	Default_Handler,	/* Reserved */
	Default_Handler,	/* Reserved */
	Default_Handler,	/* Reserved */
	Default_Handler,	/* Reserved */
	Default_Handler,	/* SVC Call */
	Default_Handler,	/* Reserved */
	Default_Handler,	/* Reserved */
	Default_Handler,	/* PendSV */
	Default_Handler,	/* SysTick */
/* External interrupt handlers follow */
	Default_Handler, 	/* 0: WWDG */
	Default_Handler, 	/* 1: PVD and VDDIO2 supply comparator interrupt */
	Default_Handler, 	/* 2: RTC */
	Default_Handler, 	/* 3: FLASH */
	Default_Handler, 	/* 4: RCC */
	button_irq_handler, 	/* 5: EXTI0_1 */
	button_irq_handler, 	/* 6: EXTI2_3 */
	button_irq_handler, 	/* 7: EXTI4_15 */
	Default_Handler, 	/* 8: TSC */
	Default_Handler, 	/* 9: DMA_CH1 */
	Default_Handler, 	/* 10: DMA_CH2_3, DMA2_CH_1_2 */
	Default_Handler, 	/* 11: DMA_CH4_5_6_7, DMA2_CH3_4_5 */
	adc_handler,     	/* 12: ADC_COMP */
	Default_Handler, 	/* 13: TIM1_BRK_UP_TRG_COM */
	Default_Handler, 	/* 14: TIM1_CC */
	Default_Handler, 	/* 15: TIM2 */
	Default_Handler, 	/* 16: TIM3 */
	Default_Handler, 	/* 17: TIM6_DAC*/
	Default_Handler, 	/* 18: TIM7 */
	Default_Handler, 	/* 19: TIM14 */
	Default_Handler, 	/* 20: TIM15 */
	Default_Handler, 	/* 21: TIM16 */
	Default_Handler, 	/* 22: TIM17 */
	Default_Handler, 	/* 23: I2C1 */
	Default_Handler, 	/* 24: I2C2 */
	Default_Handler, 	/* 25: SPI1 */
	Default_Handler, 	/* 26: SPI2 */
	Default_Handler, 	/* 27: USART1 */
	Default_Handler, 	/* 28: USART2 */
	Default_Handler, 	/* 29: USART3_4_5_6_7_8 */
	Default_Handler, 	/* 30: CEC_CAN */
	Default_Handler 	/* 31: USB */
};
void init()
{
// do global/static data initialization
	unsigned char *src;
	unsigned char *dest;
	unsigned len;
	src= &INIT_DATA_VALUES;
	dest= &INIT_DATA_START;
	len= &INIT_DATA_END-&INIT_DATA_START;
	while (len--)
		*dest++ = *src++;
// zero out the uninitialized global/static variables
	dest = &BSS_START;
	len = &BSS_END - &BSS_START;
	while (len--)
		*dest++=0;
	main();
}


void Default_Handler()
{
	while(1);
}

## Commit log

2017-10-11 README: Rename project to PWM and make Max leader
2017-10-26 add in-progress preliminary eagle schematic & project
    [preliminary-board.sch]
2017-10-26 make preliminary schematic much more interesting
    [preliminary-board.sch]
2017-10-26 finished preliminary board BASED OFF OF http://ebrombaugh.studionebula.com/embedded/stm32f042breakout/stm32f042f_breakout_schematic.pdf
    [preliminary-board.sch]
2017-11-01 Add final schematic version 1
    Rename to more appropriate name
    [final_board_v1.sch]
2017-11-01 Add final schematic version 1 (#30)
    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
    [final_board_v1.sch]
2017-11-02 final schematic?
    [final-schematic.sch]
2017-11-02 actually final schematic
    [final-schematic.sch]
2017-11-02 add bypass capacitor to power supply of MCU
    [final-schematic.sch]
2017-11-06 Remove old file
    [final_board_v1.sch]
2017-11-08 add preliminary bill of materials
    [preliminary-bom.csv]
2017-11-08 Add two routing options for prelim board layout
    [final-schematic.brd, final-schematic_Alternate_Placement.brd, final-schematic_Alternate_Placement.sch]
2017-11-09 Added UART
2017-11-09 tidy schematic and board files; preliminary layout is a go!
    [final-schematic.brd, final-schematic_Alternate_Placement.sch, flextimus-prime.brd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]
2017-11-13 Using ARM CMSIS libs provided by ST (#41)
    * .gitignore: Added ctags file
    * src: Rewrote using ARM CMSIS libs provided by ST
2017-11-15 Add new board layout and schematic
    Also add new lcd driver to use later
    [flextimus-prime-final-v1.brd, flextimus-prime-final-v1.sch]
2017-11-15 adc: Added functions based off exampels
2017-11-15 adc: Pattern of adc_status returning established
2017-11-15 adc: Lock out further conversions while one is in progress
2017-11-15 gdbinit: Loads and runs kernel until error
    [adc.c, main.c]
2017-11-15 main: Added note on adc not yet working
2017-11-15 Im an idiot and was using the drivers wrong, fixing...
    [adc.c, main.c]
2017-11-15 better board
    [flextimus-prime-final-v1.brd, flextimus-prime-final-v1.sch, flextimus-prime.brd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]
2017-11-16 better board, for real
    [flextimus-prime.brd, flextimus-prime.sch]
2017-11-16 schematic + board rev 1.2
    [flextimus-prime.brd, flextimus-prime.sch]
2017-11-16 minor tweaks to board rev 1.2
    [flextimus-prime.brd, flextimus-prime.sch]
2017-11-16 Auto stash before merge of "master" and "origin/master"
    [flextimus-prime.brd, flextimus-prime.sch]
2017-11-16 minor trace tweak
    [flextimus-prime.brd]
2017-11-16 Add minor fixes for board
    Removes DRC error for overlap
    Increases width of missed power trace
    [flextimus-prime.brd]
2017-11-19 Add support and test for HD44780 LCD driver
    Needs commenting and clean up, but
    test code works with HD44780
2017-11-19 WIP Code. Needs lots of work.
    Just the basic framework I had laid out the other day. Needs a lot of work and probably doesn't even compile yet.
    [main.c, test.c]
2017-11-22 Makefile: Find ARM toolchain version dynamicly
2017-11-22 Makefile: Fix dynamicly getting ARM toolchain version
2017-11-24 adc: Conversion working
2017-11-24 adc: Started transition to interrupts
2017-11-27 adc: Random things almost have interrupts working
2017-11-27 adc: Added some ADC watchdog code
    For some reason this is jumping to the Default handler. Last commit it
    correctlyl goes to the adc_handler. This needs to be fixed.
    [adc.c, gpio.c, gpio.h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]
2017-11-29 adc: Interrupt are not quite working, sometims working sometimes not, propably and ordering issue
    [adc.c, gpio.c, init.c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]
2017-11-29 Fix LCD 2 row mode
    Fixes a missed set up instruction
    [hd44780.c]
2017-11-29 adc: adc_handler was triggered
2017-11-30 adc: ADC conversion interrupt working
2017-11-30 adc: Watchdog code primed
2017-11-30 adc: adc_down powers off ADC
2017-11-30 gpio: Button interrupts working
2017-11-30 Button test reading from ADC
2017-11-30 adc: continuous capture
2017-11-30 adc: Continuous conversion fixes
    [adc.c, main.c]
2017-11-30 adc: Start max and min at 2000
2017-11-30 adc: No longer using unknown conversions from examples
    [adc.c]
2017-11-30 adc: Fixed channel config
    [adc.c]
2017-11-30 main: flextimus_prime_config_pressed configures ADC watchdog
2017-12-01 main: Using continous conversion instead of ADC AWD
2017-12-01 Updated Bill of Materials
2017-12-01 LCD pin headers added
2017-12-02 Redefine flex sensor GPIO
    [config.h, gpio.h]
2017-12-02 Fix ADC priority
2017-12-02 main: Only buzz if we have been configured once before
    [main.c]
2017-12-02 Added include/stm32f042.h
2017-12-02 Removed Flex sensor old init
    [main.c]
2017-12-03 gpio: Added button debouncing
2017-12-03 main: Config LED as buzzer
    [config.h, main.c]
2017-12-05 Messages work, most everything works.
    TODO: Make it so bad posture message doesn't constantly write
    [config.h, main.c]
2017-12-06 Last commit, fix two small bugs
    Button debounce delay increased, and now we don't beep unless you've been configured at least once.
    [main.c]
2017-12-06 tidy up
    [preliminary-board.sch, preliminary-bom.csv]
2017-12-06 more tidy up?
    [flextimus-prime.brd, flextimus-prime.sch]

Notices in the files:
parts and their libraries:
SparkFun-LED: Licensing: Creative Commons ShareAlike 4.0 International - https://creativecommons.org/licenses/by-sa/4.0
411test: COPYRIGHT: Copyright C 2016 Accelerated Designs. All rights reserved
